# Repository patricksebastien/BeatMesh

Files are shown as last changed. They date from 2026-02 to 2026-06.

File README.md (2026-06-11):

# BeatMesh

A module to synchronize via Ableton Link, MIDI, or CV clock. 

Built with PlatformIO and the ESP-IDF framework (espressif32), BeatMesh acts as a hub to keep your hardware and software locked in time.

## 🚀 Features

- **10x MIDI Out ports**
- **Flexible Routing:** Send raw MIDI to all 10 outputs OR filter to keep only the MIDI clock.
- **CV Integration:** CV clock and reset outputs.
- **Ableton Link:** Synchronize seamlessly over WiFi.
- **OTA Firmware Updates:** Upload new firmware (`.bin`) directly from the web portal — no cable needed.
- **Easy Soldering:** All through-hole components, beginner-friendly assembly.

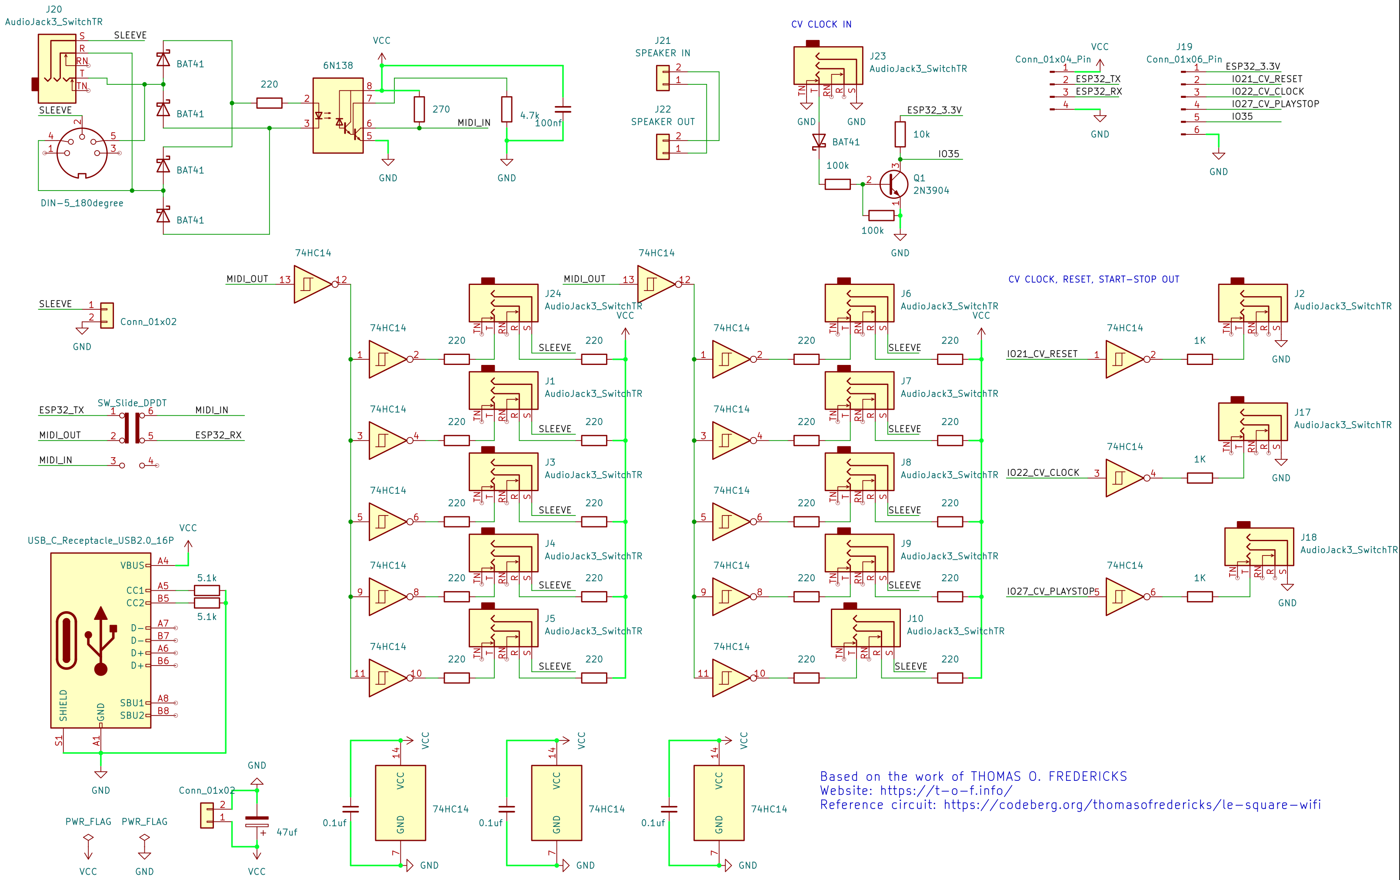
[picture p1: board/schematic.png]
Schematic


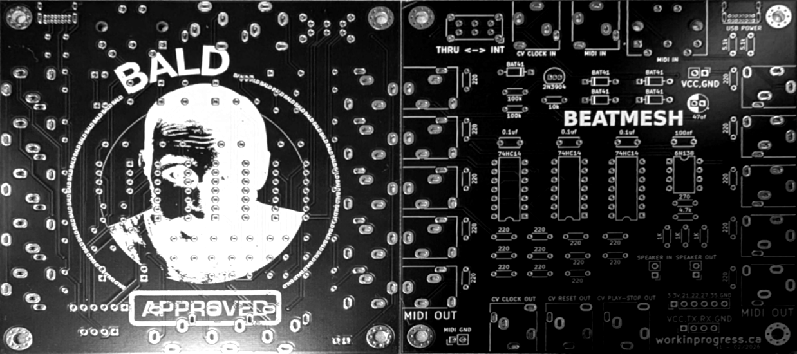
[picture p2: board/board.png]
Board


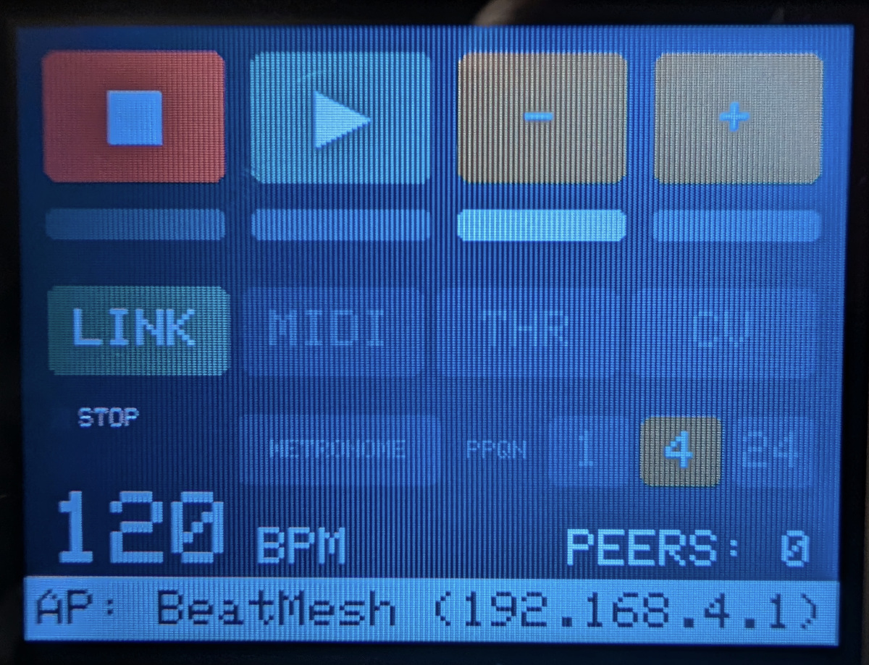
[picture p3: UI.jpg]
UI


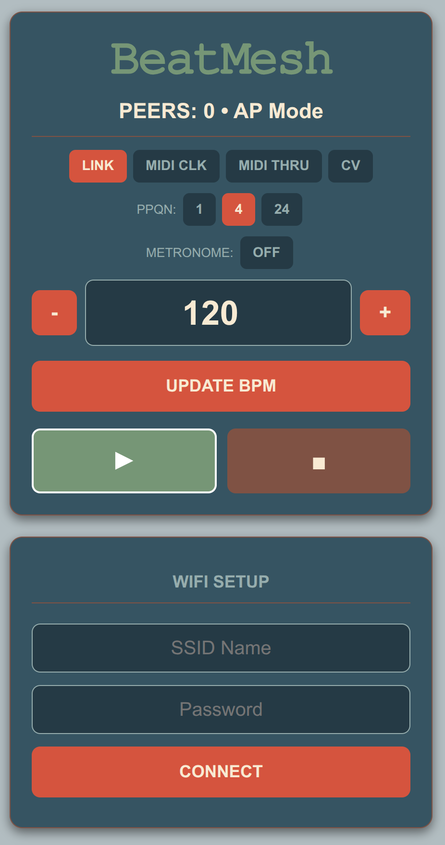
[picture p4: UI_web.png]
Web UI


---

## 🎛️ Custom PCB (KiCad)

The repository includes a production-ready printed circuit board designed in **KiCad 10**. You can find the source files (`.kicad_sch` and `.kicad_pcb`) in the `board/` directory.

> ⚠️ **V1 PCB Errata:** The 2-pin power connector near the USB-C port has its silkscreen polarity printed incorrectly. The actual pinout is **GND, VCC** (not VCC, GND as silkscreened). Wire accordingly to avoid damage.

### Hardware Design Highlights:
- **Form Factor:** 100mm x 100mm, 2-layer board (optimized for low-cost fabrication).
- **MIDI Input:** Fully opto-isolated using a **6N138** optocoupler. The circuit is properly level-shifted to send safe 3.3V logic to the ESP32, while powering the optocoupler with 5V for fast, reliable data transmission.
- **10x MIDI Outputs:** Buffered (using 2N3904 NPN transistors) and split to drive up to 10 distinct devices simultaneously without signal degradation. Designed with space-saving 3.5mm TRS jacks (SJ1-3515N).
- **CV / Sync Out:** Capable of sending analog clock, reset, and play/stop signals to Eurorack/modular gear. Includes **BAT41** Schottky diodes for signal protection.
- **CYD Integration:** Designed to interface cleanly with the Cheap Yellow Display (ESP32-2432S028R) ecosystem via standard 2.54mm pin headers.
- **Power Delivery:** Robust decoupling with 100nF ceramics and 47µF (25V) electrolytics to keep clock and CV paths stable and noise-free.

---

## 💻 Installation & Dependencies

> Built with ESP-IDF v5.5.0

External components live under `components/` as git submodules pinned to the versions used in this project:

| Submodule | Upstream | Pinned at |
|---|---|---|
| `components/asio/asio` | [chriskohlhoff/asio](https://github.com/chriskohlhoff/asio) | `asio-1-32-0` |
| `components/esp_abl_link` | [docwilco/esp_abl_link](https://github.com/docwilco/esp_abl_link) | `v3.1.5-1` |
| `components/esp_abl_link/vendor/ableton-link` | [Ableton/link](https://github.com/Ableton/link) | `Link-3.1.5` |
| `components/LovyanGFX` | [lovyan03/LovyanGFX](https://github.com/lovyan03/LovyanGFX) | `1.2.19` |

### Cloning

```bash
git clone --recurse-submodules https://github.com/patricksebastien/BeatMesh.git
```

If you already cloned without `--recurse-submodules`:

```bash
git submodule update --init --recursive
```

> Use `git config --global url."https://github.com/".insteadOf git@github.com:` if you don't have ssh key configured.

### ASIO Patch (Required)
To prevent the ESP32 from rebooting during transient network errors (e.g., `send_to ENOMEM`), ASIO needs a small patch. Link recovers from packet loss gracefully, so we do not want `std::terminate` to abort the program.

Apply the patch shipped in this repo:

```bash
git -C components/asio/asio apply ../../../patches/asio-esp32-rethrow-fix.patch
```

---

## ⚙️ Configuration Files

### 1. `platformio.ini`
Add the following to your environment configuration to ensure correct serial speeds, flash sizing, and ASIO compatibility:

```ini
monitor_speed = 115200
board_upload.flash_size = 4MB
board_build.partitions = huge_app.csv

build_flags = 
    -fexceptions
    -D ASIO_STANDALONE
    -D ASIO_NO_TYPEID
```

### 2. `huge_app.csv` (Partition Table)
Create this file in the root directory. Link and LovyanGFX make the binary quite large, so the default partition table is too small.

```csv
# Name,   Type, SubType, Offset,  Size, Flags
nvs,      data, nvs,     ,        0x4000,
otadata,  data, ota,     ,        0x2000,
phy_init, data, phy,     ,        0x1000,
factory,  app,  factory, ,        0x300000,
```

### 3. `sdkconfig.defaults`
Create this file in the root directory. These settings configure flash size/speed, enable C++ exceptions (required for ASIO/Link), and set the partition table layout.

```ini
# Flash Size & Speed (CYD has a 4MB Flash chip)
CONFIG_ESPTOOLPY_FLASHSIZE_4MB=y
CONFIG_ESPTOOLPY_FLASHFREQ_80M=y
CONFIG_ESPTOOLPY_FLASHMODE_QIO=y

# C++ Exceptions (Required for ASIO/Link)
CONFIG_COMPILER_CXX_EXCEPTIONS=y
CONFIG_COMPILER_CXX_RTTI=y

# Partition Table Layout
CONFIG_PARTITION_TABLE_SINGLE_APP_LARGE=y

# CPU Frequency (Ensure Link timing on Core 1 and Display/WiFi on Core 0 run smoothly)
CONFIG_ESP_DEFAULT_CPU_FREQ_240=y

# LWIP (Networking for Link - Multicast support is crucial)
CONFIG_LWIP_MAX_SOCKETS=16
CONFIG_LWIP_IGMP=y

# Common NVS/WiFi Settings
CONFIG_ESP_WIFI_AUTH_PHASE2_ENABLED=y
CONFIG_BT_ENABLED=n
```

### 4. `src/CMakeLists.txt`
Include the necessary libraries via `REQUIRES` so ESP-IDF links them properly:

```cmake
idf_component_register(SRCS "main.cpp"
                    INCLUDE_DIRS "."
                    REQUIRES LovyanGFX esp_http_server nvs_flash esp_wifi esp_event esp_abl_link)
```

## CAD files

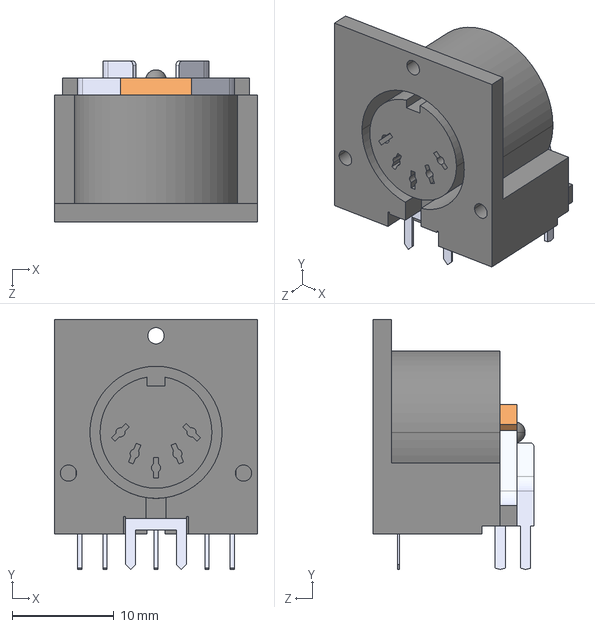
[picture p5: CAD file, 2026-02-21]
board/SDS-50J.step
20.0 x 24.6 x 15.8 mm

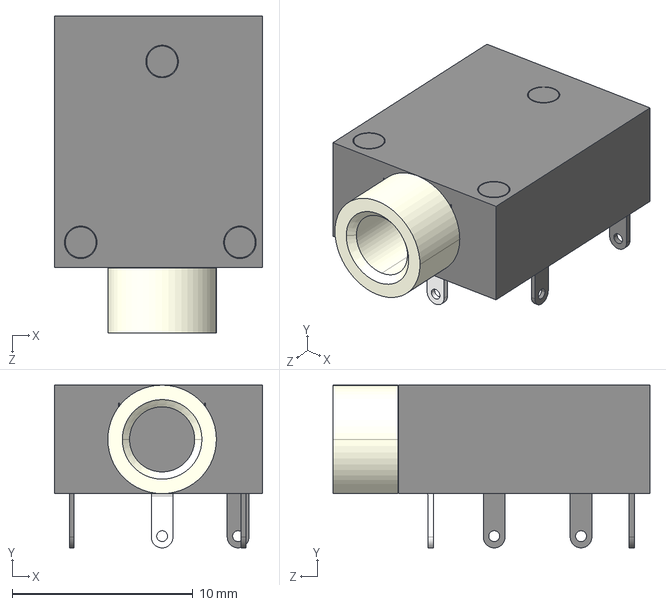
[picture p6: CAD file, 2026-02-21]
board/Same_Sky_SJ1-3515N.step
11.5 x 9.00 x 17.5 mm

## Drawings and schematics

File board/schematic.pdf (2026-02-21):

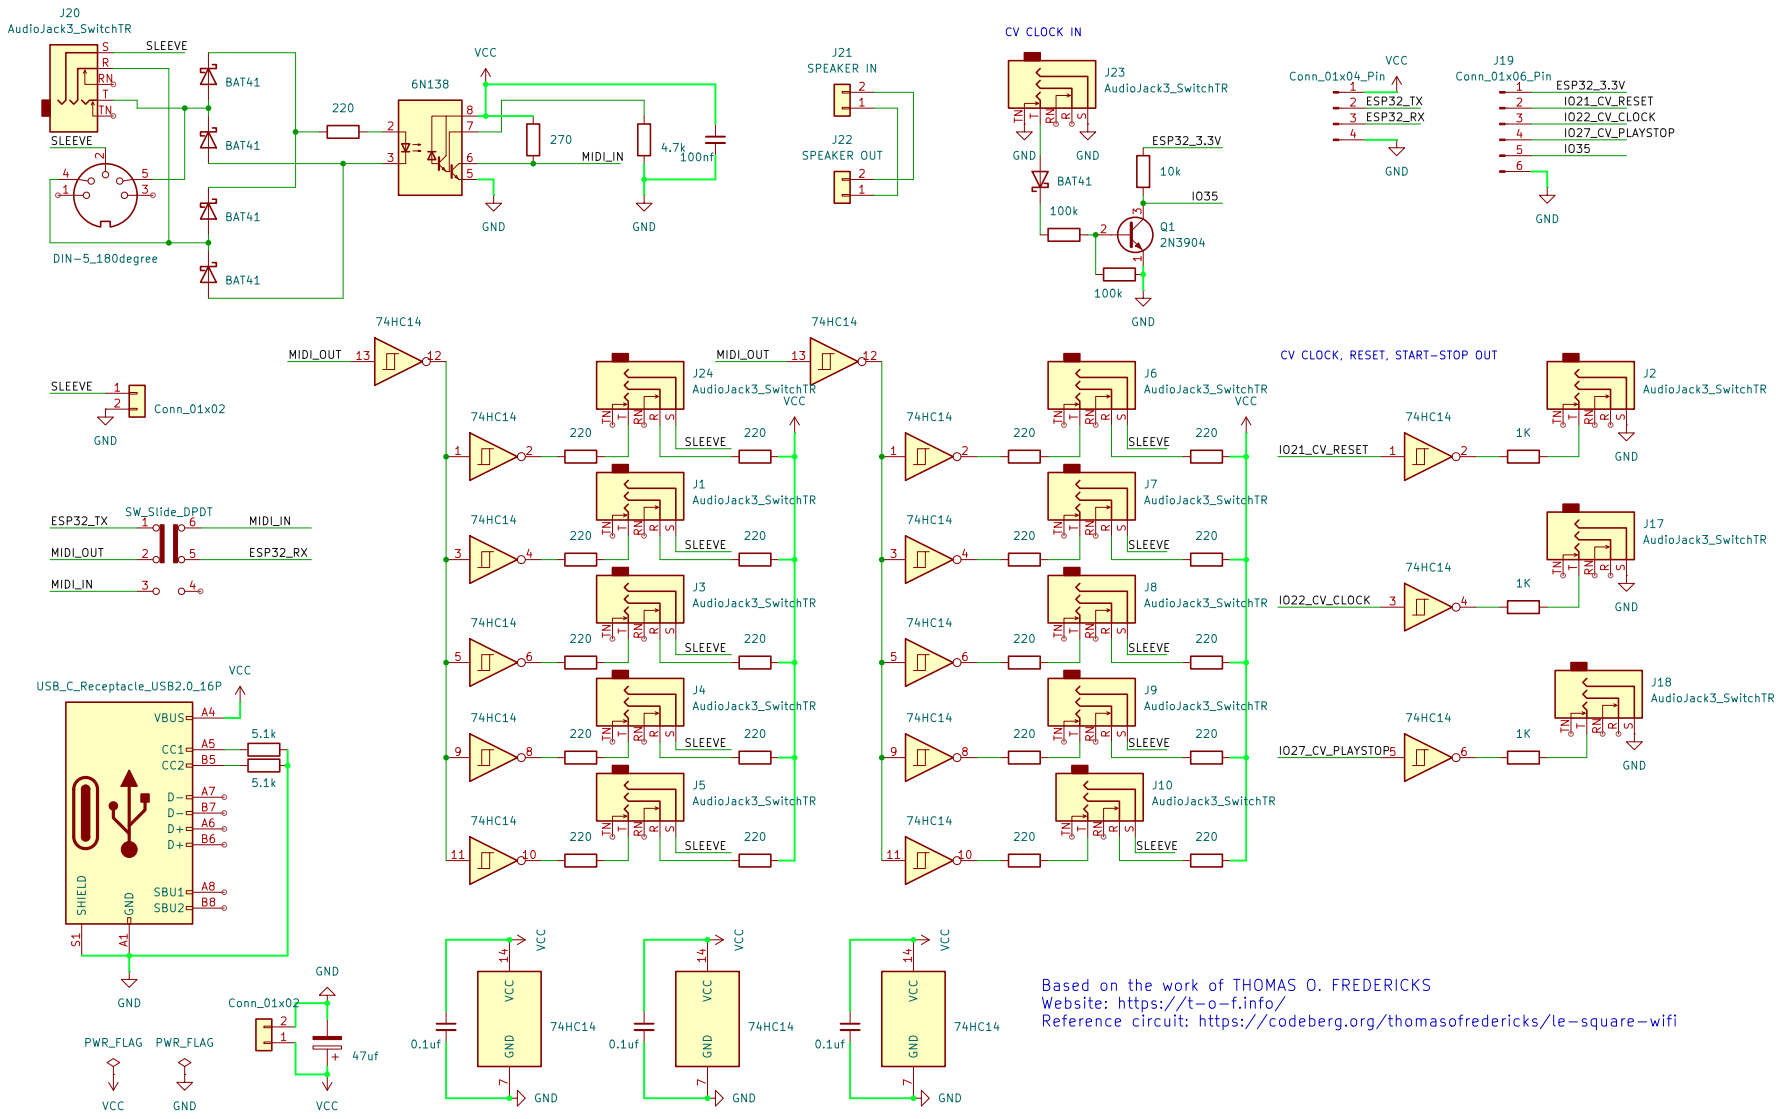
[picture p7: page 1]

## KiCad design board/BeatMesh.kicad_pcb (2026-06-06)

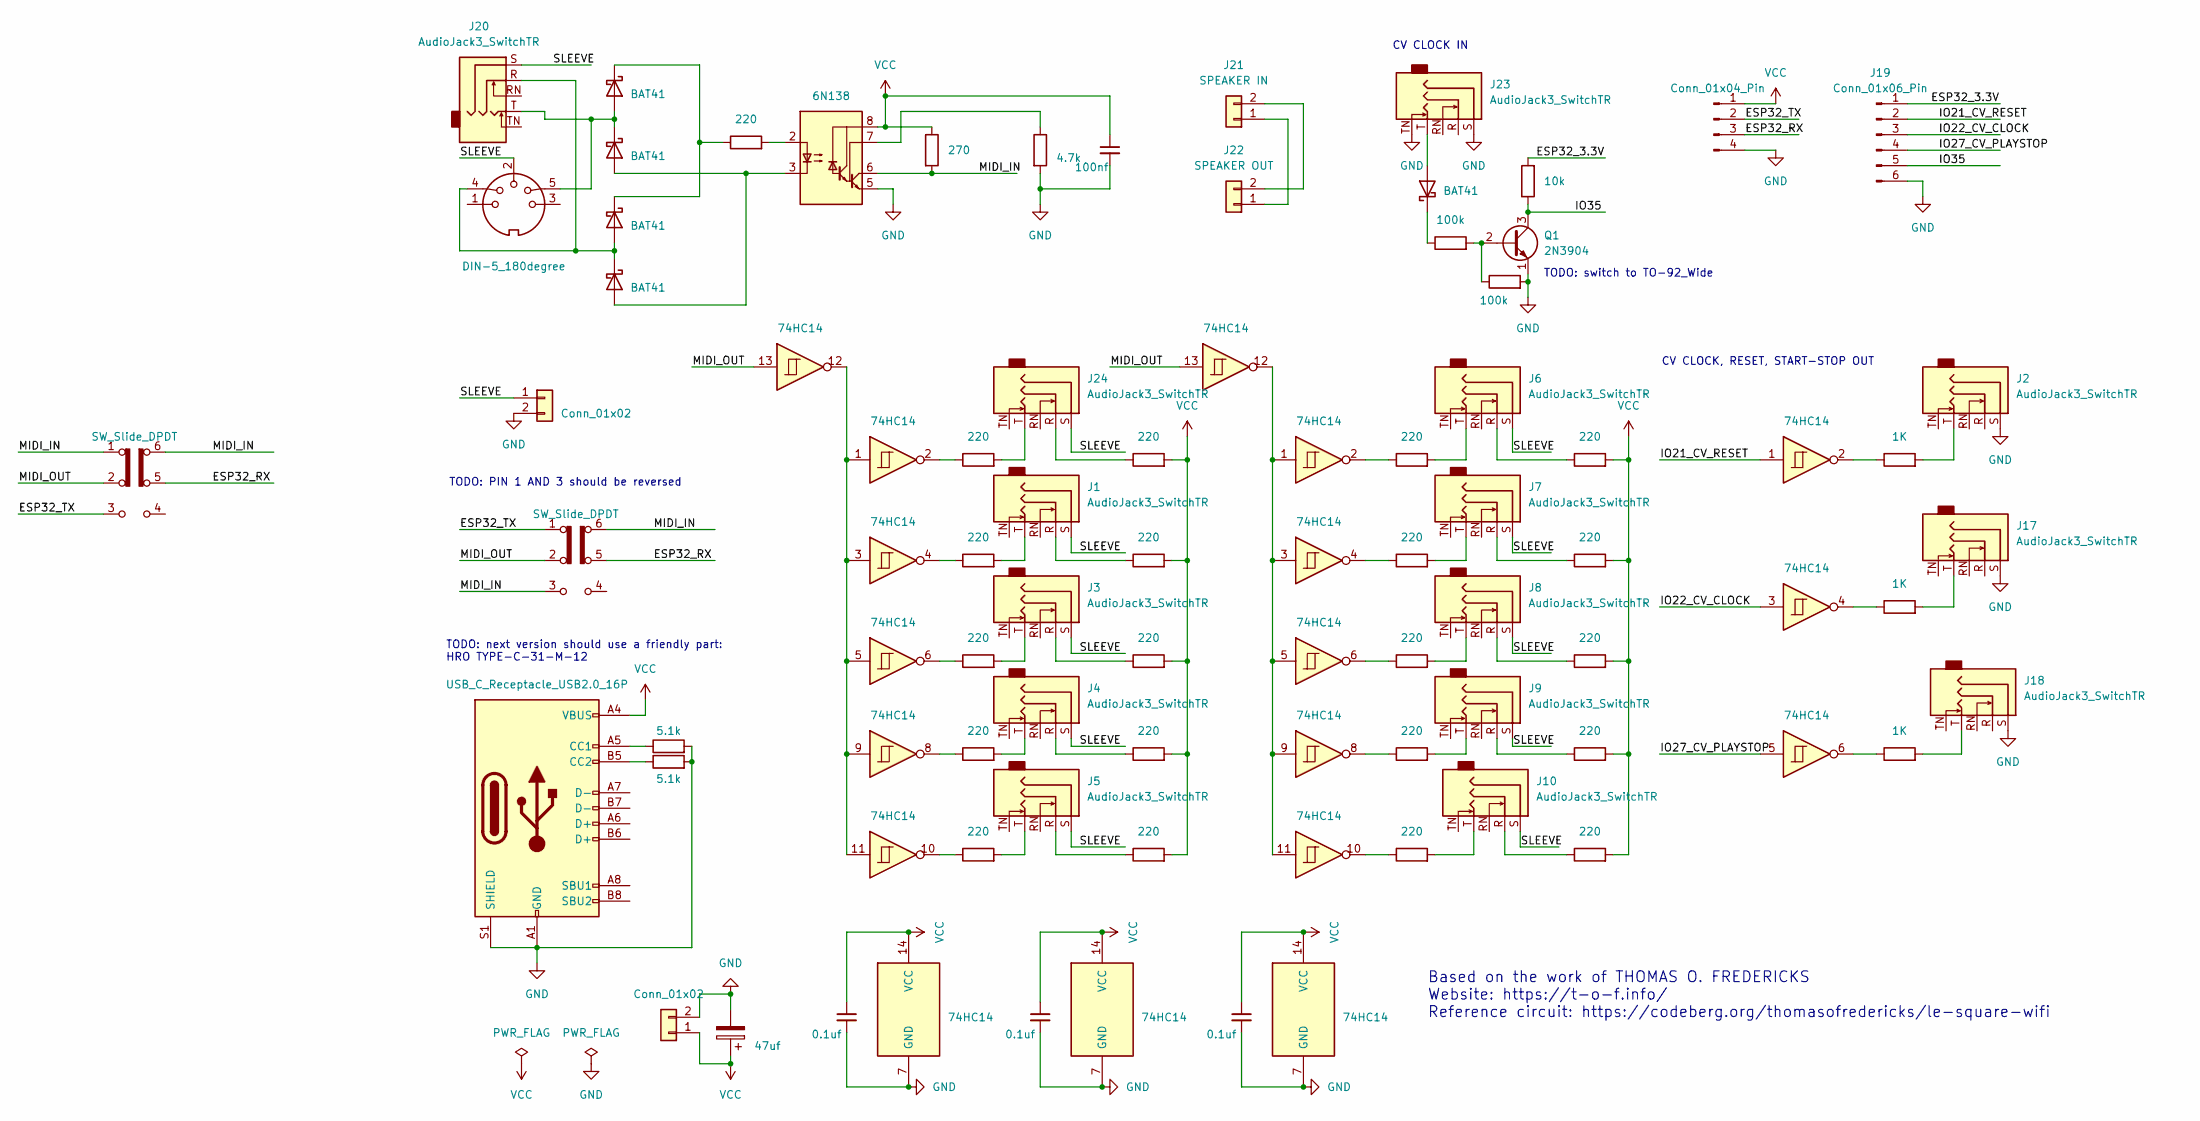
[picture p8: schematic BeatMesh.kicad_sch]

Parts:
C1, C2, C6: 0.1uf; C_Disc_D5.0mm_W2.5mm_P5.00mm
C3: 100nf; C_Disc_D5.0mm_W2.5mm_P5.00mm
C4: 47uf; CP_Radial_D5.0mm_P2.00mm
D1, D2, D3, D4, D6: BAT41; D_DO-35_SOD27_P7.62mm_Horizontal
J1, J2, J3, J4, J5, J6, J7, J8, J9, J10, J17, J18, J20, J23, J24: AudioJack3_SwitchTR; Jack_3.5mm_CUI_SJ1-3515N_Horizontal
J12: DIN-5_180degree; CUI_SDS-50J
J13: USB_C_Receptacle_USB2.0_16P; USB_C_Receptacle_GCT_USB4085
J14: Conn_01x04_Pin; PinHeader_1x04_P2.54mm_Vertical
J15, J16: Conn_01x02; PinHeader_1x02_P2.54mm_Vertical
J19: Conn_01x06_Pin; PinHeader_1x06_P2.54mm_Vertical
J21: SPEAKER IN; PinHeader_1x02_P2.54mm_Vertical
J22: SPEAKER OUT; PinHeader_1x02_P2.54mm_Vertical
Q1: 2N3904; TO-92_Inline
R1, R6, R7, R8, R9, R10, R11, R12, R13, R14, R15, R16, R17, R18, R19, R20, R21, R22, R23, R24, R25: 220; R_Axial_DIN0204_L3.6mm_D1.6mm_P5.08mm_Horizontal
R2, R3: 5.1k; R_Axial_DIN0204_L3.6mm_D1.6mm_P5.08mm_Horizontal
R4: 270; R_Axial_DIN0204_L3.6mm_D1.6mm_P5.08mm_Horizontal
R5: 4.7k; R_Axial_DIN0204_L3.6mm_D1.6mm_P5.08mm_Horizontal
R26, R27, R28: 1K; R_Axial_DIN0204_L3.6mm_D1.6mm_P5.08mm_Horizontal
R29, R31: 100k; R_Axial_DIN0204_L3.6mm_D1.6mm_P5.08mm_Horizontal
R30: 10k; R_Axial_DIN0204_L3.6mm_D1.6mm_P5.08mm_Horizontal
SW1, SW2: SW_Slide_DPDT; SW_E-Switch_EG2219_DPDT_Angled
U1, U2, U4: 74HC14; DIP-14_W7.62mm
U3: 6N138; DIP-8_W7.62mm

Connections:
/ESP32_3.3V: J19.1, R30.2
/ESP32_RX: J14.3, SW1.5 (B), SW2.5 (B)
/ESP32_TX: J14.2, SW1.1 (A), SW2.3 (C)
/IO21_CV_RESET: J19.2, U4.1
/IO22_CV_CLOCK: J19.3, U4.3
/IO27_CV_PLAYSTOP: J19.4, U4.5
/IO35: J19.5, Q1.3 (C), R30.1
/MIDI_IN: R4.2, SW1.3 (C), SW1.6 (C), SW2.1 (A), SW2.6 (C), U3.6 (VO2)
/MIDI_OUT: SW1.2 (B), SW2.2 (B), U1.13, U2.13
/SLEEVE: J1.S, J3.S, J4.S, J5.S, J6.S, J7.S, J8.S, J9.S, J10.S, J12.2, J15.1, J20.S, J24.S
GND: C1.2, C2.2, C3.2, C4.2, C6.2, J2.S, J13.A1 (GND), J13.A12 (GND), J13.B1 (GND), J13.B12 (GND), J13.S1 (SHIELD), J14.4, J15.2, J16.2, J17.S, J18.S, J19.6, J23.S, J23.TN, Q1.1 (E), R2.2, R3.2, R5.2, R31.2, U1.7 (GND), U2.7 (GND), U3.5 (GND), U4.7 (GND)
unnamed: D1.2 (A), D2.1 (K), J12.5, J20.T
unnamed: D1.1 (K), D3.1 (K), R1.1
unnamed: D2.2 (A), D4.2 (A), U3.3 (C2)
unnamed: D3.2 (A), D4.1 (K), J12.4, J20.R
unnamed: D6.2 (A), J23.T
unnamed: D6.1 (K), R29.1
unnamed: J1.R, R12.1
unnamed: J1.T, R7.2
unnamed: J2.T, R26.2
unnamed: J3.R, R13.1
unnamed: J3.T, R8.2
unnamed: J4.R, R14.1
unnamed: J4.T, R9.2
unnamed: J5.R, R15.1
unnamed: J5.T, R10.2
unnamed: J6.R, R21.1
unnamed: J6.T, R16.2
unnamed: J7.R, R22.1
unnamed: J7.T, R17.2
unnamed: J8.R, R23.1
unnamed: J8.T, R18.2
unnamed: J9.R, R24.1
unnamed: J9.T, R19.2
unnamed: J10.R, R25.1
unnamed: J10.T, R20.2
unnamed: J13.A5 (CC1), R2.1
unnamed: J13.B5 (CC2), R3.1
unnamed: J17.T, R28.2
unnamed: J18.T, R27.2
unnamed: J21.1, J22.1
unnamed: J21.2, J22.2
unnamed: J24.R, R11.1
unnamed: J24.T, R6.2
unnamed: Q1.2 (B), R29.2, R31.1
unnamed: R6.1, U2.2
unnamed: R7.1, U2.4
unnamed: R8.1, U2.6
unnamed: R9.1, U2.8
unnamed: R10.1, U2.10
unnamed: R16.1, U1.2
unnamed: R17.1, U1.4
unnamed: R18.1, U1.6
unnamed: R19.1, U1.8
unnamed: R20.1, U1.10
unnamed: R26.1, U4.2
unnamed: R27.1, U4.6
unnamed: R28.1, U4.4
unnamed: U1.1, U1.3, U1.5, U1.9, U1.11, U1.12
unnamed: U2.1, U2.3, U2.5, U2.9, U2.11, U2.12
unnamed: R1.2, U3.2 (C1)
unnamed: R5.1, U3.7 (VO1)
VCC: C1.1, C2.1, C3.1, C4.1, C6.1, J13.A4 (VBUS), J13.A9 (VBUS), J13.B4 (VBUS), J13.B9 (VBUS), J14.1, J16.1, R4.1, R11.2, R12.2, R13.2, R14.2, R15.2, R21.2, R22.2, R23.2, R24.2, R25.2, U1.14 (VCC), U2.14 (VCC), U3.8 (VCC), U4.14 (VCC)

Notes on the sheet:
Based on the work of THOMAS O. FREDERICKS Website: https://t-o-f.info/ Reference circuit: https://codeberg.org/thomasofredericks/le-square-wifi
CV CLOCK IN
CV CLOCK, RESET, START-STOP OUT
TODO: switch to TO-92_Wide
TODO: next version should use a friendly part: HRO TYPE-C-31-M-12
TODO: PIN 1 AND 3 should be reversed

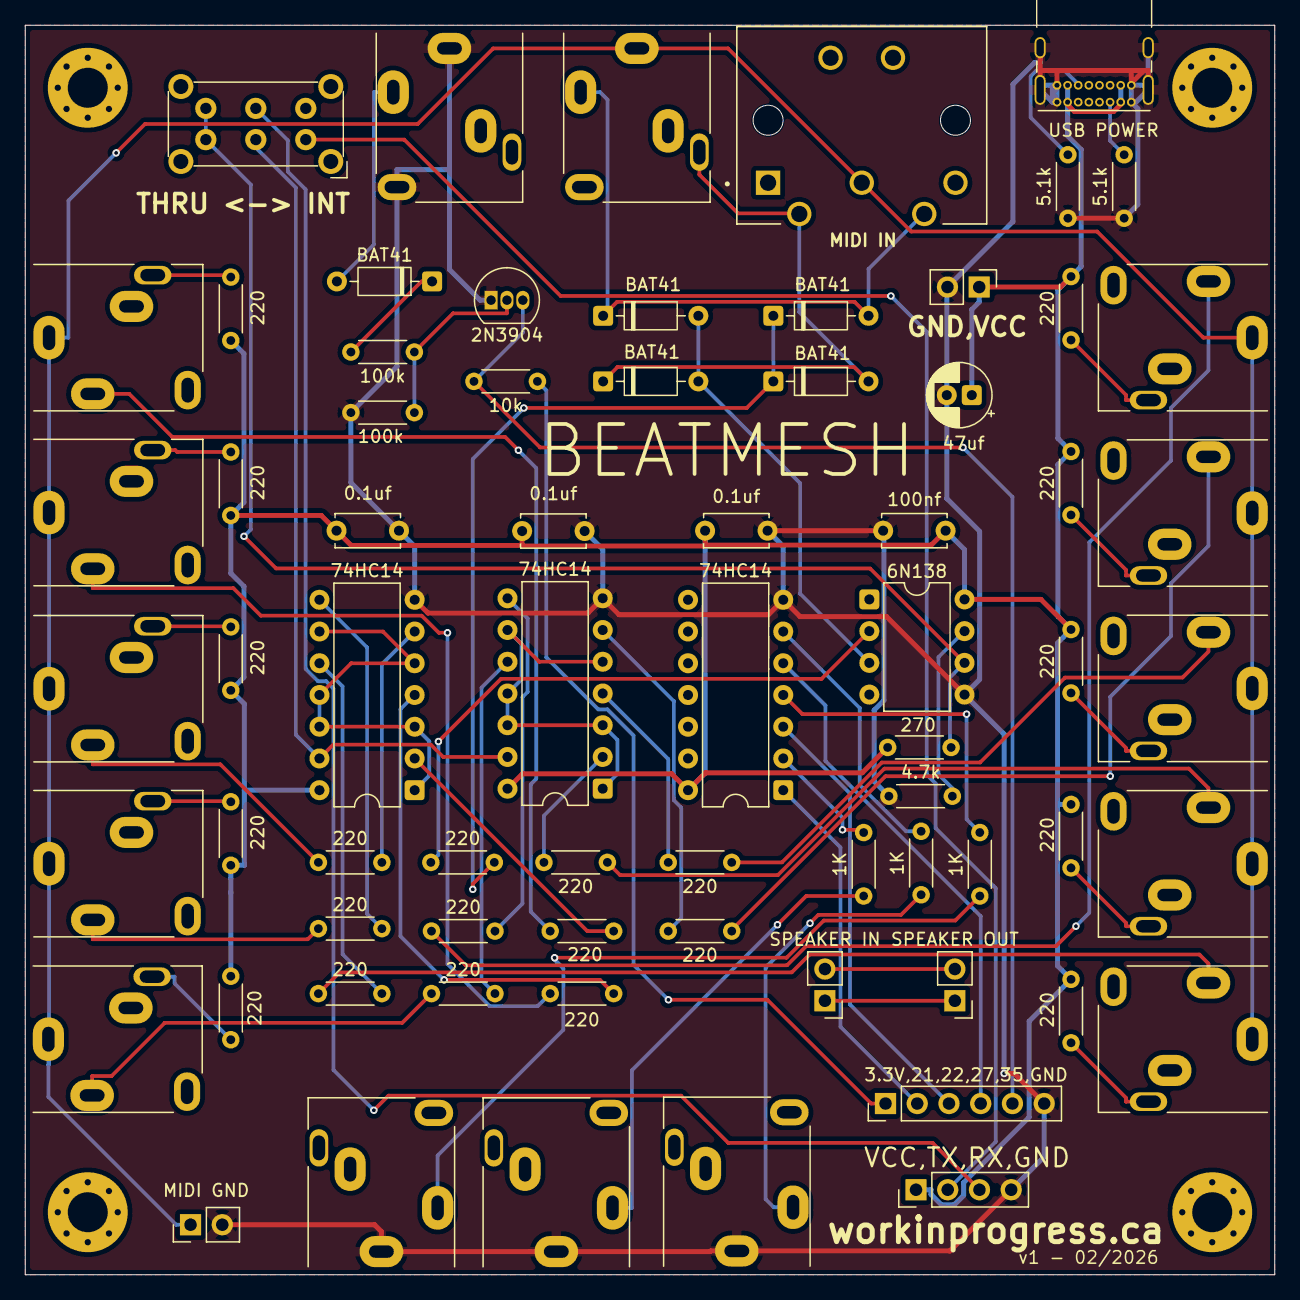
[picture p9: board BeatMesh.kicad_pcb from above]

Board: 2 copper layers, 100.0 x 100.0 mm, 74 parts (0 on the bottom side), 63 nets.

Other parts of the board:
DH1, DH2, DH3, DH4: MountingHole_3.2mm_M3_Pad_Via

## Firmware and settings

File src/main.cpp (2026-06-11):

#include <stdio.h>
#include <stdint.h>
#include <string.h>
#include <math.h>
#include "freertos/FreeRTOS.h"
#include "freertos/task.h"
#include "freertos/event_groups.h"
#include "esp_log.h"
#include "esp_wifi.h"
#include "esp_event.h"
#include "esp_http_server.h"
#include "nvs_flash.h"
#include "driver/gpio.h"
#include "driver/uart.h"
#include "driver/gptimer.h"
#include "esp_timer.h"
#include "driver/ledc.h"
#include "lwip/sockets.h"
#include "abl_link.h"
#include "esp_private/esp_clk.h"
#include "esp_heap_caps.h" 

// --- LovyanGFX Configuration (CYD) ---
#define LGFX_USE_V1
#include <LovyanGFX.hpp>

class LGFX_CYD : public lgfx::LGFX_Device {
    lgfx::Panel_ILI9341 _panel_instance;
    lgfx::Bus_SPI       _bus_instance;
    lgfx::Light_PWM     _light_instance;
    lgfx::Touch_XPT2046 _touch_instance; 
public:
    LGFX_CYD() {
        {
            auto cfg = _bus_instance.config();
            cfg.spi_host = VSPI_HOST;
            cfg.spi_mode = 0;
            cfg.freq_write = 40000000;
            cfg.pin_sclk = 14; cfg.pin_mosi = 13; cfg.pin_miso = 12; cfg.pin_dc = 2;
            _bus_instance.config(cfg);
            _panel_instance.setBus(&_bus_instance);
        }
        {
            auto cfg = _panel_instance.config();
            cfg.pin_cs = 15; cfg.pin_rst = -1;
            cfg.panel_width = 240; cfg.panel_height = 320;
            _panel_instance.config(cfg);
        }
        {
            auto cfg = _light_instance.config();
            cfg.pin_bl = 21; cfg.freq = 44100; cfg.pwm_channel = 7;
            _light_instance.config(cfg);
            _panel_instance.setLight(&_light_instance); 
        }
        { 
            auto cfg = _touch_instance.config();
            cfg.x_min = 200;  cfg.x_max = 3800; 
            cfg.y_min = 3700; cfg.y_max = 200;
            cfg.pin_int = 36; cfg.bus_shared = false; cfg.offset_rotation = 0;
            cfg.spi_host = HSPI_HOST; 
            cfg.pin_sclk = 25; cfg.pin_mosi = 32; cfg.pin_miso = 39; cfg.pin_cs = 33;
            _touch_instance.config(cfg);
            _panel_instance.setTouch(&_touch_instance);
        }
        setPanel(&_panel_instance);
    }
};

static LGFX_CYD *tft = NULL;
static const char *TAG = "BeatMesh_HUB";

// --- Global State ---
#define LED_RED            GPIO_NUM_4
#define BTN_BOOT           GPIO_NUM_0 
#define LED_ON             0           
#define LED_OFF            1
#define MAX_WIFI_RETRIES   10

static EventGroupHandle_t wifi_event_group;
static bool s_is_connected = false;
static bool s_portal_active = false;
static int s_retry_num = 0;
static char s_ssid_name[33] = {0}; 

// --- Color Macros ---
#define C_VINTAGE_BG      tft->color565(36, 72, 85)
#define C_VINTAGE_RUST    tft->color565(230, 72, 51)
#define C_VINTAGE_SAGE    tft->color565(255, 255, 255)
#define C_VINTAGE_BROWN   tft->color565(135, 79, 65)
#define C_VINTAGE_CREAM   tft->color565(251, 233, 208)
#define C_VINTAGE_FERN    tft->color565(109, 151, 115)
#define C_VINTAGE_CREAM_DIM tft->color565(122, 128, 121)
#define C_VINTAGE_AMBER   tft->color565(195, 110, 45)
#define C_VINTAGE_BG_LT   tft->color565(55, 95, 108)

// --- Mode/PPQN button layout (y=100, h=40) ---
static const int mode_btn_x[] = { 10, 86, 162, 238 };
static const int mode_btn_w[] = { 71, 71, 71, 72 };
static const int ppqn_btn_x = 162;   // single cycling button (tap to advance), right after METRONOME
static const int ppqn_btn_w = 71;
static const char *mode_labels[] = { "LINK", "MIDI", "THR", "CV" };
static const char *ppqn_labels[] = { "1", "2", "4", "8", "24", "48" };

typedef struct { 
    abl_link link; 
    abl_link_session_state session_state; 
} link_state_t;

static link_state_t g_link_state;
enum midi_mode_t { MODE_LINK = 0, MODE_MIDI_CLK = 1, MODE_MIDI_THRU = 2, MODE_CV = 3, MODE_COUNT = 4 };
static volatile int midi_mode = MODE_LINK;

// Shared PPQN setting for CV in/out — single button cycles through these
static volatile int cv_ppqn = 4;
static const int cv_ppqn_options[] = { 1, 2, 4, 8, 24, 48 };
static const int cv_ppqn_count = 6;
static volatile int cv_ppqn_idx = 2; // index into cv_ppqn_options (default: 4 PPQN)

// Metronome (LEDC PWM on GPIO 26 → onboard amp/speaker)
static volatile bool metronome_enabled = false;
#define METRO_PIN GPIO_NUM_26

// --- MIDI Monitor (small UI box, left of metronome button) ---
static portMUX_TYPE g_mon_mux = portMUX_INITIALIZER_UNLOCKED;
static char g_midi_mon_l1[10] = "MONITOR:";
static char g_midi_mon_l2[12] = "No midi in";
static volatile uint32_t g_midi_mon_seq = 0;
static volatile int64_t g_midi_mon_last_us = 0;
// Parser running-status state (only touched by midi_in_task)
static uint8_t g_mon_status = 0;
static uint8_t g_mon_data[2];
static uint8_t g_mon_data_idx = 0;
static uint8_t g_mon_data_needed = 0;

// --- MIDI Clock (UART2 routed to CYD's UART0 header pins via GPIO matrix) ---
// Board net ESP32_TX = GPIO 1 (U0TXD), ESP32_RX = GPIO 3 (U0RXD).
// Using UART_NUM_2 on these pins avoids touching the boot-ROM UART0 driver,
// but the GPIO mux will steal GPIO1/3 from UART0 — USB serial console stops
// working once midi_init() runs. Disconnect/close the USB serial monitor when
// feeding MIDI in, otherwise the host CDC chip will drive GPIO 3 against the opto.
#define MIDI_UART       UART_NUM_2
#define MIDI_TX_PIN     1
#define MIDI_RX_PIN     3
#define MIDI_BAUD       31250
#define MIDI_TICK_PERIOD 100  // Timer period in microseconds (10kHz polling)

// --- CV Clock input (GPIO35, input-only pin) ---
#define CV_CLK_PIN      GPIO_NUM_35

static volatile int32_t cv_interval_us = 0;  // atomic on 32-bit MCU
static TaskHandle_t cv_task_handle = NULL;

static void IRAM_ATTR cv_clock_isr(void *arg) {
    static int64_t last_edge = 0;  // ISR-local, no torn-read risk
    int64_t now = esp_timer_get_time();
    int64_t delta = now - last_edge;
    last_edge = now;
    if (delta > 0 && delta < INT32_MAX)
        cv_interval_us = (int32_t)delta;  // atomic 32-bit write
    BaseType_t wake = pdFALSE;
    if (cv_task_handle)
        vTaskNotifyGiveFromISR(cv_task_handle, &wake);
    if (wake) portYIELD_FROM_ISR();
}

static void cv_clock_init(void) {
    gpio_config_t io_conf = {
        .pin_bit_mask = (1ULL << CV_CLK_PIN),
        .mode = GPIO_MODE_INPUT,
        .pull_up_en = GPIO_PULLUP_DISABLE,
        .pull_down_en = GPIO_PULLDOWN_DISABLE,
        .intr_type = GPIO_INTR_POSEDGE,
    };
    gpio_config(&io_conf);
    gpio_install_isr_service(0);
    gpio_isr_handler_add(CV_CLK_PIN, cv_clock_isr, NULL);
}

// --- CV Clock output (Link → CV gates/triggers, always active) ---
// Dedicated pins from SD card connector (no conflicts)
#define CV_OUT_CLK_PIN      GPIO_NUM_22  // CV Clock (CYD IO22, not a strapping pin)
#define CV_OUT_RESET_PIN    GPIO_NUM_27  // CYD IO27 (expansion header) → CV Reset
// #define CV_OUT_RUN_PIN      GPIO_NUM_18  // SD_SCK → CV Play/Stop (disabled: modular gear uses Clock+Reset only)
#define CV_PULSE_WIDTH_US   5000         // 5ms trigger pulse

static void cv_out_init(void) {
    gpio_config_t io_conf = {
        .pin_bit_mask = (1ULL << CV_OUT_CLK_PIN) | (1ULL << CV_OUT_RESET_PIN), // | (1ULL << CV_OUT_RUN_PIN),
        .mode = GPIO_MODE_OUTPUT,
        .pull_up_en = GPIO_PULLUP_DISABLE,
        .pull_down_en = GPIO_PULLDOWN_DISABLE,
        .intr_type = GPIO_INTR_DISABLE,
    };
    gpio_config(&io_conf);
    gpio_set_level(CV_OUT_CLK_PIN, 0);
    gpio_set_level(CV_OUT_RESET_PIN, 0);
    // gpio_set_level(CV_OUT_RUN_PIN, 0);
}

static void metronome_init(void) {
    ledc_timer_config_t timer_cfg = {
        .speed_mode = LEDC_LOW_SPEED_MODE,
        .duty_resolution = LEDC_TIMER_10_BIT,
        .timer_num = LEDC_TIMER_0,
        .freq_hz = 1200,
        .clk_cfg = LEDC_AUTO_CLK,
    };
    ledc_timer_config(&timer_cfg);

    ledc_channel_config_t ch_cfg = {
        .gpio_num = METRO_PIN,
        .speed_mode = LEDC_LOW_SPEED_MODE,
        .channel = LEDC_CHANNEL_0,
        .intr_type = LEDC_INTR_DISABLE,
        .timer_sel = LEDC_TIMER_0,
        .duty = 0,
        .hpoint = 0,
    };
    ledc_channel_config(&ch_cfg);
}

static void midi_init(void) {
    uart_config_t uart_cfg = {
        .baud_rate = MIDI_BAUD,
        .data_bits = UART_DATA_8_BITS,
        .parity = UART_PARITY_DISABLE,
        .stop_bits = UART_STOP_BITS_1,
        .flow_ctrl = UART_HW_FLOWCTRL_DISABLE,
        .rx_flow_ctrl_thresh = 0,
    };
    uart_param_config(MIDI_UART, &uart_cfg);
    uart_set_pin(MIDI_UART, MIDI_TX_PIN, MIDI_RX_PIN, UART_PIN_NO_CHANGE, UART_PIN_NO_CHANGE);
    uart_driver_install(MIDI_UART, 512, 256, 0, NULL, 0);
    // Default RXFIFO threshold is 120 bytes = ~38ms of silence before ISR fires at MIDI baud.
    // Set to 1 so the ISR fires on the very first byte (~us wakeup).
    uart_set_rx_full_threshold(MIDI_UART, 1);
}

static void midi_send_tick(void) {
    const uint8_t b = 0xF8;
    uart_write_bytes(MIDI_UART, (const char *)&b, 1);
}

static void midi_send_start(void) {
    const uint8_t b = 0xFA;
    uart_write_bytes(MIDI_UART, (const char *)&b, 1);
}

static void midi_send_stop(void) {
    const uint8_t b = 0xFC;
    uart_write_bytes(MIDI_UART, (const char *)&b, 1);
}

static void midi_send_continue(void) {
    const uint8_t b = 0xFB;
    uart_write_bytes(MIDI_UART, (const char *)&b, 1);
}

static void midi_mon_publish(const char *l1, const char *l2) {
    portENTER_CRITICAL(&g_mon_mux);
    strncpy(g_midi_mon_l1, l1, sizeof(g_midi_mon_l1));
    g_midi_mon_l1[sizeof(g_midi_mon_l1) - 1] = 0;
    strncpy(g_midi_mon_l2, l2, sizeof(g_midi_mon_l2));
    g_midi_mon_l2[sizeof(g_midi_mon_l2) - 1] = 0;
    g_midi_mon_last_us = esp_timer_get_time();
    g_midi_mon_seq++;
    portEXIT_CRITICAL(&g_mon_mux);
}

static void midi_mon_byte(uint8_t b) {
    // System realtime: single-byte, doesn't disturb running status
    if (b >= 0xF8) {
        const char *name = NULL;
        switch (b) {
            case 0xF8: name = "CLK";   break;
            case 0xFA: name = "START"; break;
            case 0xFB: name = "CONT";  break;
            case 0xFC: name = "STOP";  break;
            case 0xFF: name = "RSET";  break;
        }
        if (name) midi_mon_publish(name, "");
        return;
    }
    // Status byte
    if (b >= 0x80) {
        // if (b == 0xF6) { midi_mon_publish("TUNE", ""); g_mon_status = 0; return; }
        g_mon_status = b;
        g_mon_data_idx = 0;
        switch (b & 0xF0) {
            case 0x80: case 0x90: case 0xA0: case 0xB0: case 0xE0: g_mon_data_needed = 2; break;
            case 0xC0: case 0xD0: g_mon_data_needed = 1; break;
            case 0xF0:
                if (b == 0xF1 || b == 0xF3)      g_mon_data_needed = 1;
                else if (b == 0xF2)              g_mon_data_needed = 2;
                else                             g_mon_data_needed = 0;
                break;
            default: g_mon_data_needed = 0; break;
        }
        return;
    }
    // Data byte
    if (g_mon_status == 0 || g_mon_data_needed == 0) return;
    g_mon_data[g_mon_data_idx++] = b;
    if (g_mon_data_idx < g_mon_data_needed) return;
    g_mon_data_idx = 0;

    char l1[10], l2[12];
    if (g_mon_status >= 0xF0) {
        switch (g_mon_status) {
            // case 0xF1: snprintf(l1, sizeof(l1), "MTC");  snprintf(l2, sizeof(l2), "%d", g_mon_data[0]); break;
            // case 0xF2: { int p = (g_mon_data[1] << 7) | g_mon_data[0];
            //              snprintf(l1, sizeof(l1), "SPP");  snprintf(l2, sizeof(l2), "%d", p); break; }
            // case 0xF3: snprintf(l1, sizeof(l1), "SONG"); snprintf(l2, sizeof(l2), "%d", g_mon_data[0]); break;
            default: g_mon_status = 0; return;
        }
        g_mon_status = 0;
    } else {
        uint8_t st = g_mon_status & 0xF0;
        uint8_t ch = (g_mon_status & 0x0F) + 1;
        switch (st) {
            case 0x80:
                snprintf(l1, sizeof(l1), "OFF c%d", ch);
                snprintf(l2, sizeof(l2), "%d v%d", g_mon_data[0], g_mon_data[1]);
                break;
            case 0x90:
                snprintf(l1, sizeof(l1), g_mon_data[1] ? "NOTE c%d" : "OFF c%d", ch);
                snprintf(l2, sizeof(l2), "%d v%d", g_mon_data[0], g_mon_data[1]);
                break;
            // case 0xA0:
            //     snprintf(l1, sizeof(l1), "AT c%d", ch);
            //     snprintf(l2, sizeof(l2), "%d:%d", g_mon_data[0], g_mon_data[1]);
            //     break;
            case 0xB0:
                snprintf(l1, sizeof(l1), "CC c%d", ch);
                snprintf(l2, sizeof(l2), "%d:%d", g_mon_data[0], g_mon_data[1]);
                break;
            case 0xC0:
                snprintf(l1, sizeof(l1), "PRG c%d", ch);
                snprintf(l2, sizeof(l2), "%d", g_mon_data[0]);
                break;
            // case 0xD0:
            //     snprintf(l1, sizeof(l1), "CHP c%d", ch);
            //     snprintf(l2, sizeof(l2), "%d", g_mon_data[0]);
            //     break;
            // case 0xE0: {
            //     int pb = ((g_mon_data[1] << 7) | g_mon_data[0]) - 8192;
            //     snprintf(l1, sizeof(l1), "PB c%d", ch);
            //     snprintf(l2, sizeof(l2), "%d", pb);
            //     break;
            // }
            default: return;
        }
    }
    midi_mon_publish(l1, l2);
}

// Timer ISR: notify MIDI task every 100us
static bool IRAM_ATTR midi_timer_alarm_cb(gptimer_handle_t timer,
    const gptimer_alarm_event_data_t *edata, void *user_ctx) {
    BaseType_t high_task_wakeup = pdFALSE;
    vTaskNotifyGiveFromISR((TaskHandle_t)user_ctx, &high_task_wakeup);
    return high_task_wakeup == pdTRUE;
}

static void midi_clock_task(void *param) {
    link_state_t *s = (link_state_t *)param;

    // Own session state to avoid races with visual_task
    abl_link_session_state midi_ss = abl_link_create_session_state();

    // Initialize tick counters to current position (avoid burst on start)
    abl_link_capture_audio_session_state(s->link, midi_ss);
    uint64_t now = abl_link_clock_micros(s->link);
    double beat0 = abl_link_beat_at_time(midi_ss, now, 1.0);
    int last_midi_ticks = (int)floor(beat0 * 24.0);
    int last_cv_ticks = (int)floor(beat0 * (double)cv_ppqn);
    bool last_playing = abl_link_is_playing(midi_ss);

    // Setup gptimer: 1MHz resolution, 100us alarm period
    gptimer_handle_t timer = NULL;
    gptimer_config_t timer_cfg = {
        .clk_src = GPTIMER_CLK_SRC_DEFAULT,
        .direction = GPTIMER_COUNT_UP,
        .resolution_hz = 1000000,
    };
    gptimer_new_timer(&timer_cfg, &timer);

    gptimer_alarm_config_t alarm_cfg = {
        .alarm_count = MIDI_TICK_PERIOD,
        .reload_count = 0,
        .flags = { .auto_reload_on_alarm = true },
    };
    gptimer_set_alarm_action(timer, &alarm_cfg);

    gptimer_event_callbacks_t cbs = {
        .on_alarm = midi_timer_alarm_cb,
    };
    gptimer_register_event_callbacks(timer, &cbs, xTaskGetCurrentTaskHandle());
    gptimer_enable(timer);
    gptimer_start(timer);

    bool midi_was_active = true;

    // CV out pulse end timestamps (0 = no active pulse)
    int64_t cv_clk_pulse_end = 0;
    int64_t cv_reset_pulse_end = 0;
    bool cv_last_playing = last_playing;
    int cached_cv_ppqn = cv_ppqn;  // track ppqn changes to re-snap ticks

    while (true) {
        ulTaskNotifyTake(pdTRUE, portMAX_DELAY);

        abl_link_capture_audio_session_state(s->link, midi_ss);
        now = abl_link_clock_micros(s->link);
        bool playing = abl_link_is_playing(midi_ss);
        double beat = abl_link_beat_at_time(midi_ss, now, 1.0);
        int64_t now_us = (int64_t)esp_timer_get_time();

        // ---- CV OUT: always active, independent of mode ----

        // Re-snap CV tick counter if PPQN changed (prevents freeze/burst)
        int cur_ppqn = cv_ppqn;
        if (cur_ppqn != cached_cv_ppqn) {
            last_cv_ticks = (int)floor(beat * (double)cur_ppqn);
            cached_cv_ppqn = cur_ppqn;
        }

        // End active pulses that exceeded their width
        if (cv_clk_pulse_end && now_us >= cv_clk_pulse_end) {
            gpio_set_level(CV_OUT_CLK_PIN, 0);
            cv_clk_pulse_end = 0;
        }
        if (cv_reset_pulse_end && now_us >= cv_reset_pulse_end) {
            gpio_set_level(CV_OUT_RESET_PIN, 0);
            cv_reset_pulse_end = 0;
        }

        // Start/stop: reset trigger on start (run gate disabled)
        if (playing && !cv_last_playing) {
            // gpio_set_level(CV_OUT_RUN_PIN, 1);
            gpio_set_level(CV_OUT_RESET_PIN, 1);
            cv_reset_pulse_end = now_us + CV_PULSE_WIDTH_US;
            last_cv_ticks = (int)floor(beat * (double)cur_ppqn);
        } else if (!playing && cv_last_playing) {
            // gpio_set_level(CV_OUT_RUN_PIN, 0);
            gpio_set_level(CV_OUT_CLK_PIN, 0);
            cv_clk_pulse_end = 0;
        }
        cv_last_playing = playing;

        // Clock tick pulses (uses shared cv_ppqn setting)
        if (playing) {
            int ticks = (int)floor(beat * (double)cur_ppqn);
            if (ticks > last_cv_ticks) {
                gpio_set_level(CV_OUT_CLK_PIN, 1);
                cv_clk_pulse_end = now_us + CV_PULSE_WIDTH_US;
            }
            last_cv_ticks = ticks;
        }

        // ---- MIDI OUT: active in LINK and CV modes ----
        bool midi_active = (midi_mode == MODE_LINK || midi_mode == MODE_CV);

        if (!midi_active) {
            midi_was_active = false;
            continue;
        }

        // Re-sync after returning from MIDI-in mode
        if (!midi_was_active) {
            last_playing = playing;
            last_midi_ticks = (int)floor(beat * 24.0);
            midi_was_active = true;
            continue;
        }

        // Start/stop transitions
        if (playing && !last_playing) {
            midi_send_start();
        } else if (!playing && last_playing) {
            midi_send_stop();
        }
        last_playing = playing;

        if (playing) {
            int ticks = (int)floor(beat * 24.0);
            if (ticks > last_midi_ticks) {
                midi_send_tick();
            }
            last_midi_ticks = ticks;
        }
    }
}
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
extern "C" void app_main(void) {
    esp_log_level_set("*", ESP_LOG_WARN);
    esp_log_level_set("httpd_parse", ESP_LOG_ERROR);
    esp_log_level_set("httpd_txrx", ESP_LOG_ERROR);
    esp_err_t ret = nvs_flash_init();
    if (ret == ESP_ERR_NVS_NO_FREE_PAGES || ret == ESP_ERR_NVS_NEW_VERSION_FOUND) {
        ESP_ERROR_CHECK(nvs_flash_erase()); ret = nvs_flash_init();
    }

    esp_netif_init(); 
    esp_event_loop_create_default();
    wifi_event_group = xEventGroupCreate();
    esp_netif_create_default_wifi_sta(); 
    esp_netif_create_default_wifi_ap();

    wifi_init_config_t cfg = WIFI_INIT_CONFIG_DEFAULT(); 
    esp_wifi_init(&cfg);
    esp_event_handler_instance_register(WIFI_EVENT, ESP_EVENT_ANY_ID, &event_handler, NULL, NULL);
    esp_event_handler_instance_register(IP_EVENT, IP_EVENT_STA_GOT_IP, &event_handler, NULL, NULL);

    g_link_state.link = abl_link_create(120.0);
    g_link_state.session_state = abl_link_create_session_state();
    g_web_ss = abl_link_create_session_state();
    abl_link_enable(g_link_state.link, true);
    abl_link_enable_start_stop_sync(g_link_state.link, true);

    uint64_t now = abl_link_clock_micros(g_link_state.link);
    abl_link_capture_app_session_state(g_link_state.link, g_link_state.session_state);
    abl_link_set_is_playing(g_link_state.session_state, true, now);
    abl_link_commit_app_session_state(g_link_state.link, g_link_state.session_state);

    // Visual task: Core 0 (display + WiFi), Link/MIDI on Core 1
    // Priority 5: Below MIDI tasks, above idle
    xTaskCreatePinnedToCore(visual_task, "visual", 8192, &g_link_state, 5, NULL, 0);

    // MIDI tasks: Core 1 (alongside Link), high priority for timing precision
    midi_init();
    cv_clock_init();
    cv_out_init();
    metronome_init();
    xTaskCreatePinnedToCore(midi_clock_task, "midi_out", 4096, &g_link_state, 10, NULL, 1);
    xTaskCreatePinnedToCore(midi_in_task, "midi_in", 4096, &g_link_state, 10, NULL, 1);

    wifi_config_t sta_cfg;
    esp_wifi_get_config(WIFI_IF_STA, &sta_cfg);
    if (strlen((char*)sta_cfg.sta.ssid) == 0) start_setup_portal();
    else { esp_wifi_set_mode(WIFI_MODE_STA); esp_wifi_start(); esp_wifi_set_ps(WIFI_PS_NONE); }
}

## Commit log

2026-05-05 using submodule - pin idf - adjusted installation doc
    [partitions.csv]
2026-05-05 restore asio
    [partitions.csv]
2026-05-07 errata V1 + updated to kicad 10
    [BeatMesh.kicad_pcb, BeatMesh.kicad_sch]
2026-05-07 kicad 10
2026-06-06 modulo for ppqn, added TODO in pcb
    [BeatMesh.kicad_pcb, BeatMesh.kicad_sch]
2026-06-11 OTA firmware update via web portal
    - Two-slot OTA partition table (ota_4mb.csv): ota_0/ota_1 at 1984KB each,
    replaces single 3MB factory app (one-time serial reflash required,
    saved WiFi credentials are wiped by the layout change)
    - /update POST endpoint streams a raw .bin into the inactive slot
    (magic-byte check, size check, esp_ota_end validation; a failed or
    interrupted upload leaves the running firmware untouched)
    - FIRMWARE UPDATE card on the web UI with file picker, upload progress,
    current version + running slot
    - Web server now also runs in STA mode (full UI reachable on the LAN)
    - mDNS: device reachable at http://beatmesh.local
    - STA IP shown on the TFT status line and web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
    [ota_4mb.csv]
2026-06-11 notes on pins
    [BeatMesh.kicad_sch]
2026-06-16 board v2
2026-10-21 stop on bar - board updated
2026-10-21 update readme with photo of UI and board connected
2026-10-21 pcb v2 doc
2026-10-21 adding 3d print info
2026-10-21 flashing play while waiting for start + stl rendered pcb
